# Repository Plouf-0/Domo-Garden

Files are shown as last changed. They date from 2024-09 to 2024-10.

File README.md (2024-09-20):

# Domo-Garden
#### A projet to add domotique in my garden

## 1. Project overview

#### Objective
Design and develop a Zigbee-based sensor network. The network will collect data from various environmental sensors (Thermal, Humidity, PH, ...), communicate wirelessly via Zigbee, and transmit data to a central hub that sends the information to a Home Assistant server via Wi-Fi. The system will also control an electrovalve based on predefined conditions.

#### Key Components:

- ESP32 + Zigbee module for Hub with Wi-Fi connectivity
- EFR32MG22-based sensor nodes
- Temperature, humidity sensors, and other IoT peripherals
- Electrovalve for irrigation control

## 2. Technical Specifications

#### Functional Requirements

    Data Collection: Periodic collection of temperature, humidity, and other sensor data.

    Communication: Use Zigbee for sensor node communication and Wi-Fi for sending data to the server.

    Control: Triggering of an electrovalve based on time or sensor data.

    Hub Features: The hub will aggregate data from up to 30 Zigbee devices and relay it via Wi-Fi to a server.

    Data Transfer Rate: Sensor data will be transmitted periodically, adjustable from 1 minute to 1 hour.

#### Hardware Specifications

    Microcontroller:
        ESP32
        EFR32MG22E224F512IM32

    Power Supply: Battery-powered nodes, possible use of solar panels. Minimum 1-month battery life without recharging. A 1000mAh = 1 year of battery life.

    Radio Frequency: Zigbee protocol.

    Communication Range: Up to 100 meters from hub, with a mesh network to cover distances up to 20 meters between each module.

    Sensors:
        Temperature sensors.
        Humidity sensors.
        Soil moisture sensors.
        Light sensors.
        PH sensors.
        More to come.

#### Software Specifications

    Programming Languages: C/C++ (for embedded systems), Python (for server-side automation).

    Development Environment: Simplicity Studio (for EFR32MG22).
    
    Protocols:
        Zigbee (3.0)
        Wi-Fi for hub (ESP32 or similar)
        MQTT (for data transmission to Home Assistant server).

    Operating System: FreeRTOS (for efficient power management).

#### Performance Metrics

    Battery Life: Minimum 30 days.

    Latency: Data transmission delay < 2 seconds between sensor reading and hub reception.

    Network Coverage: 100-meter total coverage using mesh networking.

## 3. Project Plan

#### Phases of Development

    Phase 1: Requirements Gathering & Research
        Gather requirements for sensors, control mechanisms, and networking.
        Research hardware options, compatibility with Zigbee and Home Assistant.

    Phase 2: Software Development
        Develop firmware for the EFR32MG22E224F512IM40 to read sensors, communicate via Zigbee, and send commands to the electrovalve with the EFR32xG22E Explorer Kit.
        Develop software for the Zigbee hub to manage data collection and Wi-Fi transmission to Home Assistant with the ESP32 and the Zigbee CC2530 Development Board.

    Phase 2^2: Hardware Design
        Design the PCB for sensor nodes (powered by EFR32MG22E224F512IM40).
        Create a schematic for power management (battery, solar charging).
        Select components for the electrovalve control system.
        Design and print the casing.

    Phase 3: Integration with Home Assistant
        Set up the Home Assistant server with Zigbee2MQTT or ZHA.
        Implement data visualization for sensor data.
        Test commands sent from Home Assistant to control the electrovalve.

    Phase 4: Prototyping
        Assemble and test initial sensor nodes and hub.
        Perform range and battery life tests.
        Ensure proper communication between the Zigbee nodes and the hub.

    Phase 6: Field Testing
        Deploy the system in a real environment (garden, yard).
        Monitor sensor performance, network stability, and control system reliability.

    Phase 6: Finalization & Documentation
        Finalize the design based on testing results.
        Prepare full documentation, including schematics, software, and user guide.

## 4. Risk Assessment

    Power Supply Issues: If solar panels are used, energy harvesting efficiency must be tested under various weather conditions.
    Connectivity Range: Trees and obstacles could interfere with Zigbee signals. Extensive field testing will be necessary to determine optimal node placement.
    Data Security: Implement encryption for data transmitted via Zigbee to prevent unauthorized access.
    Component Availability: Verify the supply chain for key components (e.g., EFR32MG22) to avoid potential delays due to shortages.

## 5. Additional Considerations

    OTA (Over-The-Air) Firmware Updates: Consider adding functionality for future remote firmware updates.
    Scalability: Keep flexibility in mind for expanding the network or adding more nodes later.

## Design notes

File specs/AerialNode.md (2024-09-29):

# Domo-Garden
### The node is the modular part where sensors are attached. It gets sensors information and transmit them to the hub via Zigbee.

## 1. Components

- EFR32MG22E224F512IM32
- DHT22
- Photoresistors
- Battery 1000mAh + recharging module (MCP73833)
- CP2102N-Axx-xQFN20 (USB to UART)
- TLV75533PDBV (3-5V to 3.3V)
- Crystal ECS-384-CDX-1983-TR3 

## 2. Alim

The board is powered by USB-C.
The USB-C powers the MCP73833 that recharges the 1000mAh.
The MCP73833 and the battery can power the board by using a TLV75533PDBV to sabilize the voltage to 3.3V.

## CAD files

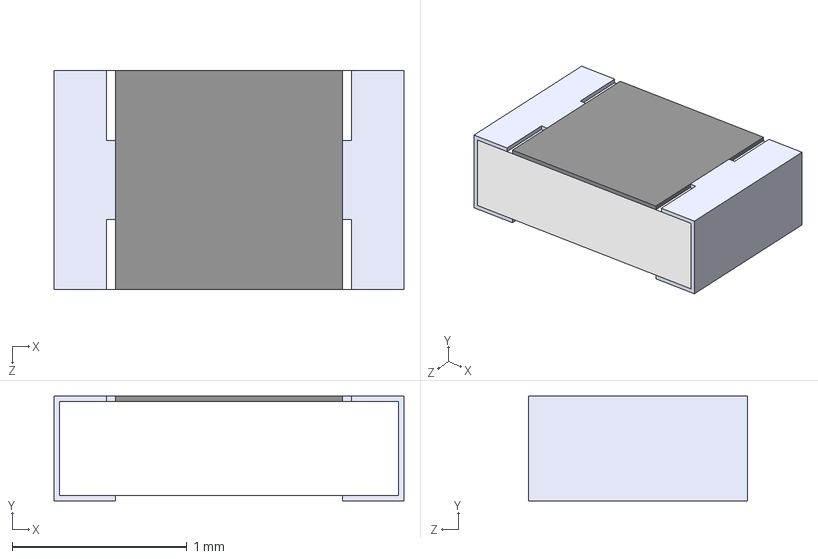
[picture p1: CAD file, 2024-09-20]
PCB/node/Components/capa10uf6.3v_CC0805KKX5R5BB106/CC0805KKX5R5BB106.step
2.00 x 0.6 x 1.25 mm

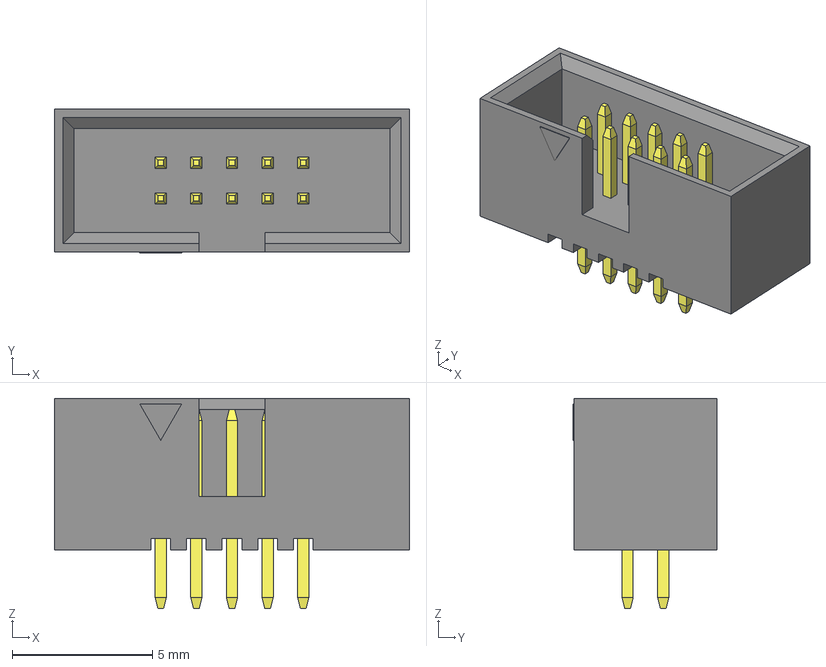
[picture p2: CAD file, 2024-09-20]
PCB/node/Components/EFR32MG22-miniboard-main/eec.models/CNC_Tech_-_3220-10-0100-00.step
12.7 x 5.13 x 7.50 mm

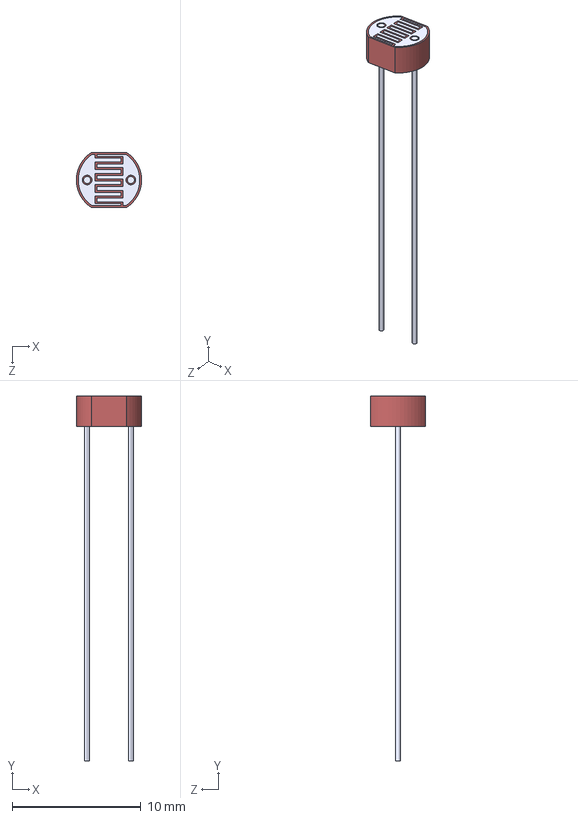
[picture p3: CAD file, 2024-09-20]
PCB/node/Components/photoresistor_PDV-P8003/PDV-P8003.step
5.07 x 28.4 x 4.29 mm

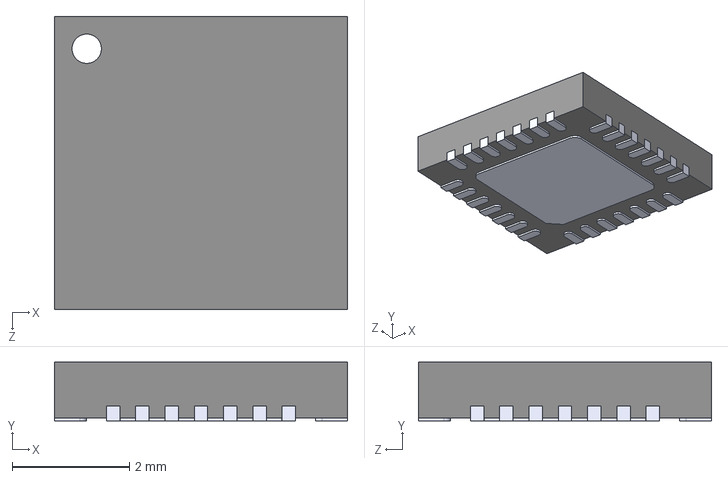
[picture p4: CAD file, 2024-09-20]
PCB/node/Components/Usb-Uart_INTERFACE-CP2102-GMR_QFN28_/INTERFACE-CP2102-GMR_QFN28_.step
5.00 x 1.00 x 5.00 mm

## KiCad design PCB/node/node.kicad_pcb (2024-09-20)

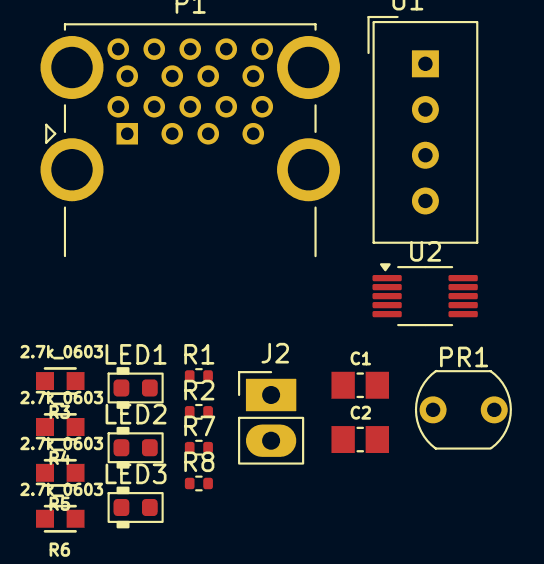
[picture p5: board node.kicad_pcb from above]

Board: 2 copper layers, 18 parts (0 on the bottom side), 12 nets, no tracks yet.

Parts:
C1, C2: 10uF 6.3V; CAPC2012X70
J2: BATT; PinHeader_1x02_P2.54mm_Vertical
LED1: LED_0603_Green; LED_0603_1608Metric
LED2: LED_0603_Yellow; LED_0603_1608Metric
LED3: LED_0603_Red; LED_0603_1608Metric
P1: USB_C_Plug_USB2.0; USB3_A_Molex_48406-0001_Horizontal_Stacked
PR1: R_LDR_5.1x4.3mm_P3.4mm_Vertical
R1, R2, R7, R8: 10k_0402; R_0402_1005Metric
R3, R4, R5, R6: 2.7k_0603; R_0603
U1: DHT22; Aosong_DHT11_5.5x12.0_P2.54mm
U2: MCP73833-xxx-UN; MSOP-10_3x3mm_P0.5mm

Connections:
+3.3V: C2.1, J2.1, R1.1, R2.1, U1.1 (VDD), U2.9 (V_{BAT}), U2.10 (V_{BAT})
DHT GPIO: R1.2, U1.2 (DATA)
GND: C1.2, C2.2, J2.2, R6.2, R7.1, R8.1, U1.4 (GND), U2.5 (V_{SS})
unnamed: C1.1, LED1.2 (A), LED2.2 (A), LED3.2 (A), U2.1 (V_{DD}), U2.2 (V_{DD})
unnamed: LED1.1 (K), R3.1
unnamed: LED2.1 (K), R4.1
unnamed: LED3.1 (K), R5.1
unnamed: R6.1, R7.2, U2.6 (PROG)
unnamed: R4.2, U2.3 (STAT1)
unnamed: R3.2, U2.4 (STAT2)
unnamed: R8.2, U2.8 (THERM)
unnamed: R5.2, U2.7 (~PG)

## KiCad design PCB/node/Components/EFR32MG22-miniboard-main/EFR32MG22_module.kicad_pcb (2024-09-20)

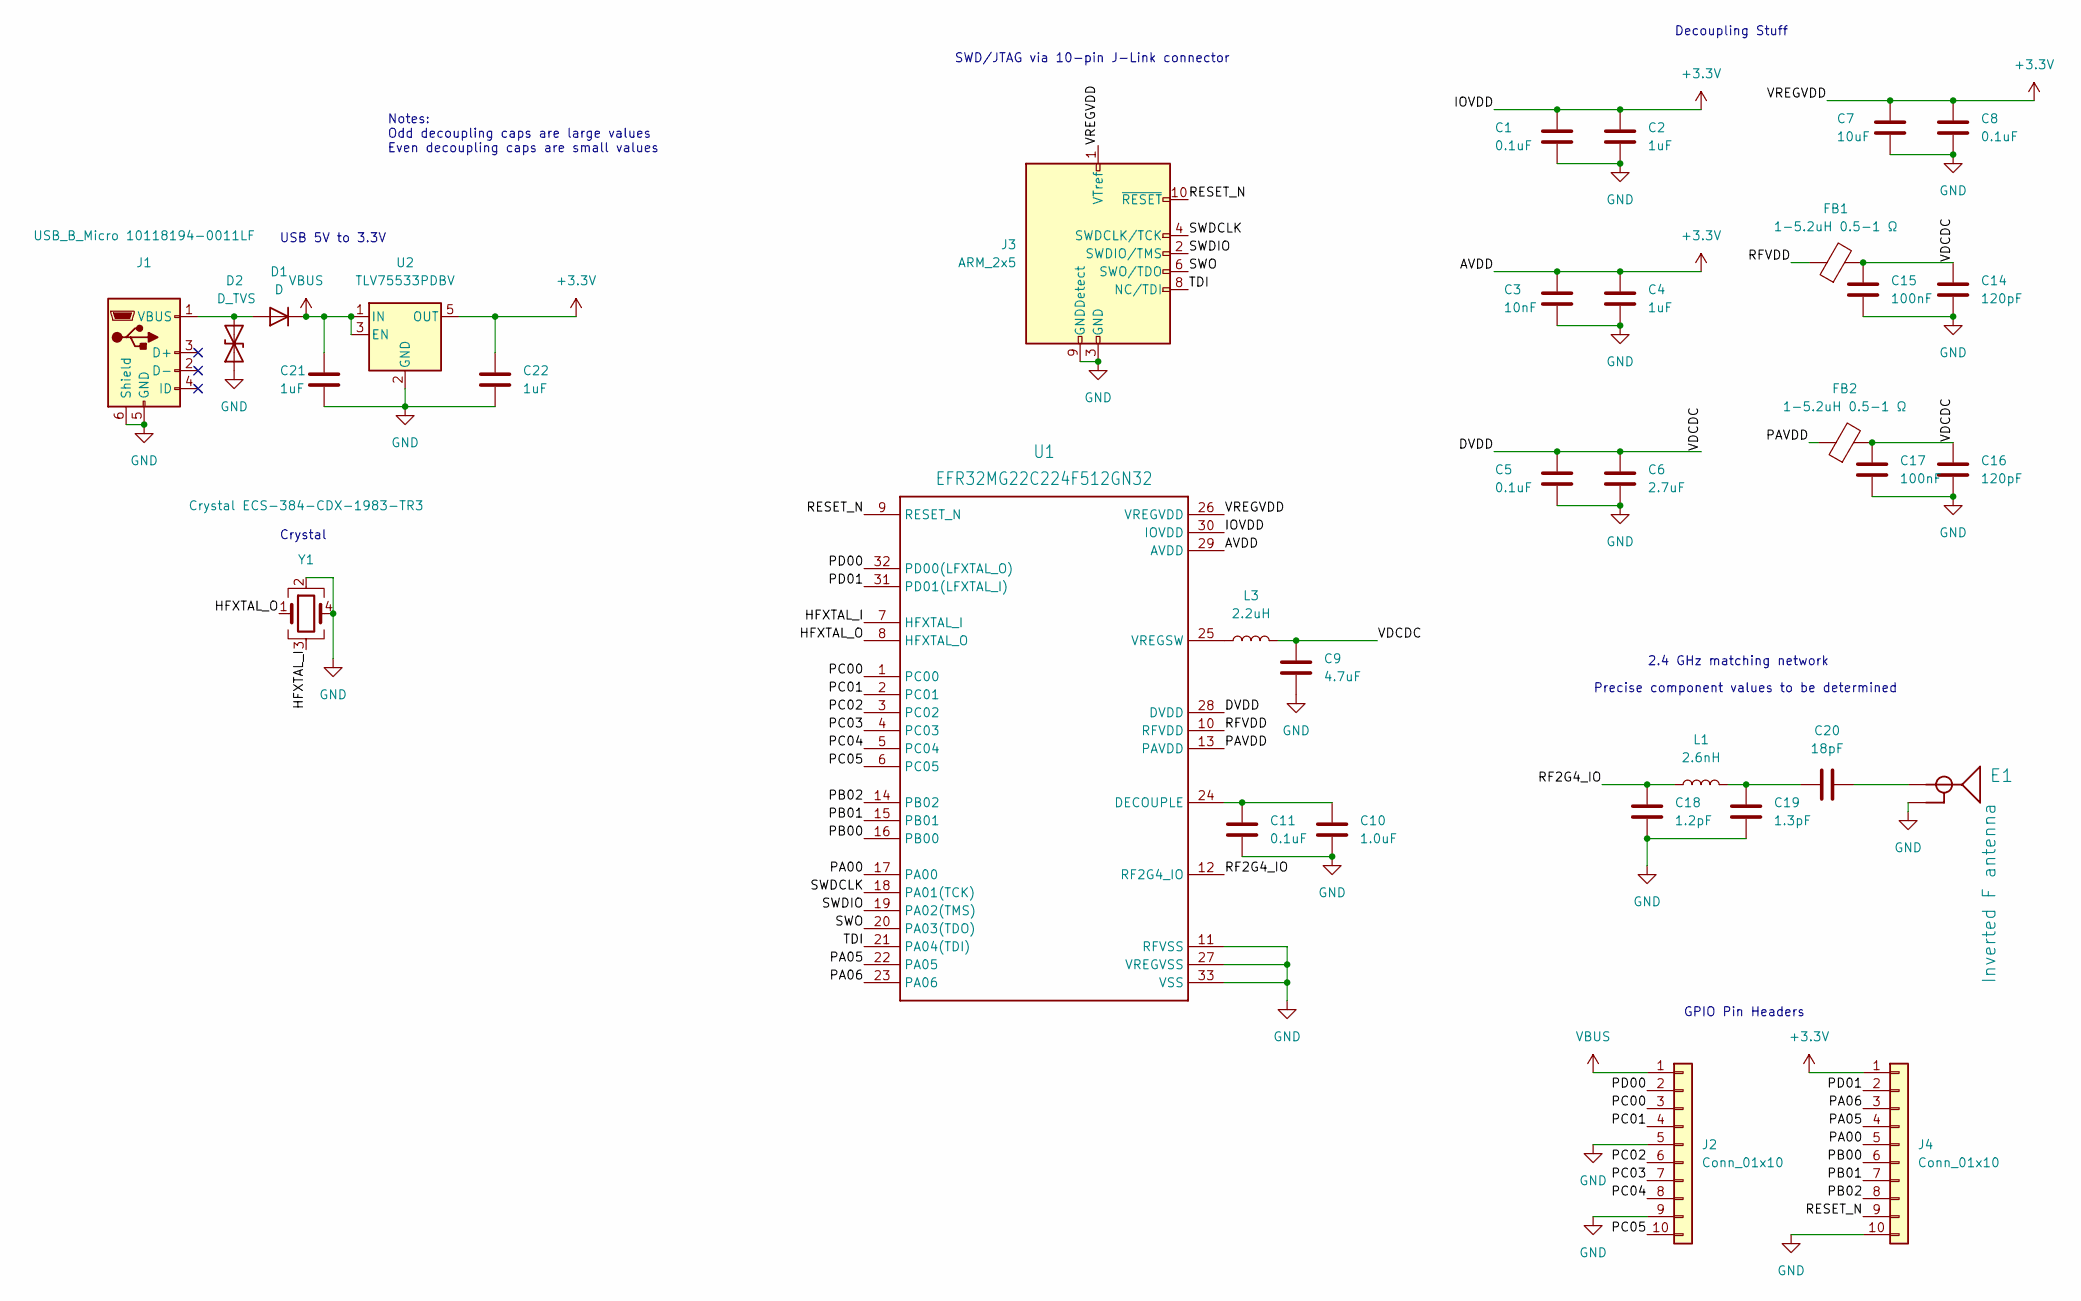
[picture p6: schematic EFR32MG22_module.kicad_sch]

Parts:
C1, C5, C8, C11: 0.1uF; C_0603_1608Metric_Pad1.08x0.95mm_HandSolder
C2, C4, C21, C22: 1uF; C_0603_1608Metric_Pad1.08x0.95mm_HandSolder
C3: 10nF; C_0603_1608Metric_Pad1.08x0.95mm_HandSolder
C6: 2.7uF; C_0603_1608Metric_Pad1.08x0.95mm_HandSolder
C7: 10uF; C_0603_1608Metric_Pad1.08x0.95mm_HandSolder
C9: 4.7uF; C_0603_1608Metric_Pad1.08x0.95mm_HandSolder
C10: 1.0uF; C_0603_1608Metric_Pad1.08x0.95mm_HandSolder
C14, C16: 120pF; C_0603_1608Metric_Pad1.08x0.95mm_HandSolder
C15, C17: 100nF; C_0603_1608Metric_Pad1.08x0.95mm_HandSolder
C18: 1.2pF; C_0603_1608Metric_Pad1.08x0.95mm_HandSolder
C19: 1.3pF; C_0603_1608Metric_Pad1.08x0.95mm_HandSolder
C20: 18pF; C_0603_1608Metric_Pad1.08x0.95mm_HandSolder
D1: D; D_SOD-123
D2: D_TVS; D_0201_0603Metric
E1: Inverted F antenna; TRACE_ANTENNA_2.4GHZ_15.2MM
FB1, FB2: 1-5.2uH 0.5-1 Ω; L_0603_1608Metric_Pad1.05x0.95mm_HandSolder
J1: USB_B_Micro 10118194-0011LF; USB_Micro-B_Amphenol_10118194_Horizontal
J2, J4: Conn_01x10; PinHeader_1x10_P2.54mm_Vertical
J3: ARM_2x5; 322010030000TR
L1: 2.6nH; L_0603_1608Metric_Pad1.05x0.95mm_HandSolder
L3: 2.2uH; L_0805_2012Metric_Pad1.15x1.40mm_HandSolder
U1: EFR32MG22C224F512GN32; QFN-32-1EP_4x4mm_P0.4mm_EP2.9x2.9mm_ThermalVias
U2: TLV75533PDBV; SOT-23-5
Y1: Crystal ECS-384-CDX-1983-TR3; Crystal_SMD_2016-4Pin_2.0x1.6mm

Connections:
+3.3V: C1.1, C2.1, C3.1, C4.1, C7.1, C8.1, C22.2, J3.1 (VTref), J4.1, U1.26 (VREGVDD), U1.29 (AVDD), U1.30 (IOVDD), U2.5 (OUT)
/DVDD: C5.1, C6.1, C9.1, C14.1, C15.1, C16.1, C17.1, FB1.2, FB2.2, L3.2, U1.28 (DVDD)
/HFXTAL_I: U1.7 (HFXTAL_I), Y1.3
/HFXTAL_O: U1.8 (HFXTAL_O), Y1.1
/PA00: J4.5, U1.17 (PA00)
/PA05: J4.4, U1.22 (PA05)
/PA06: J4.3, U1.23 (PA06)
/PAVDD: FB2.1, U1.13 (PAVDD)
/PB00: J4.6, U1.16 (PB00)
/PB01: J4.7, U1.15 (PB01)
/PB02: J4.8, U1.14 (PB02)
/PC00: J2.3, U1.1 (PC00)
/PC01: J2.4, U1.2 (PC01)
/PC02: J2.6, U1.3 (PC02)
/PC03: J2.7, U1.4 (PC03)
/PC04: J2.8, U1.5 (PC04)
/PC05: J2.10, U1.6 (PC05)
/PD00: J2.2, U1.32 (PD00(LFXTAL_O))
/PD01: J4.2, U1.31 (PD01(LFXTAL_I))
/RESET_N: J3.10 (~RESET), J4.9, U1.9 (RESET_N)
/RF2G4_IO: C18.1, L1.1, U1.12 (RF2G4_IO)
/RFVDD: FB1.1, U1.10 (RFVDD)
/SWDCLK: J3.4 (SWDCLK/TCK), U1.18 (PA01(TCK))
/SWDIO: J3.2 (SWDIO/TMS), U1.19 (PA02(TMS))
/SWO: J3.6 (SWO/TDO), U1.20 (PA03(TDO))
/TDI: J3.8 (NC/TDI), U1.21 (PA04(TDI))
GND: C1.2, C2.2, C3.2, C4.2, C5.2, C6.2, C7.2, C8.2, C9.2, C10.2, C11.2, C14.2, C15.2, C16.2, C17.2, C18.2, C19.2, C21.1, C22.1, D2.1 (A1), E1.GND, J1.5 (GND), J1.6 (Shield), J2.5, J2.9, J3.3 (GND), J3.5 (GND), J3.9 (GNDDetect), J4.10, U1.11 (RFVSS), U1.27 (VREGVSS), U1.33 (VSS), U2.2 (GND), Y1.2, Y1.4
unnamed: C10.1, C11.1, U1.24 (DECOUPLE)
unnamed: C19.1, C20.2, L1.2
unnamed: C20.1, E1.ANT (SIGNAL)
unnamed: D1.2 (A), D2.2 (A2), J1.1 (VBUS)
unnamed: L3.1, U1.25 (VREGSW)
VBUS: C21.2, D1.1 (K), J2.1, U2.1 (IN), U2.3 (EN)

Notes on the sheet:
GPIO Pin Headers
Precise component values to be determined
Notes: Odd decoupling caps are large values Even decoupling caps are small values
2.4 GHz matching network
SWD/JTAG via 10-pin J-Link connector
Crystal
Decoupling Stuff
USB 5V to 3.3V

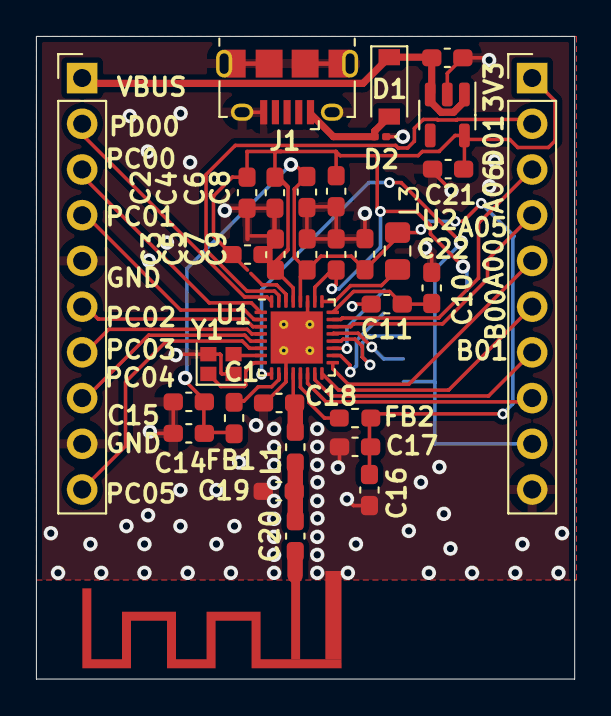
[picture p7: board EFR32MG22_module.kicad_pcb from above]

Board: 2 copper layers, 29.9 x 35.7 mm, 34 parts (1 on the bottom side), 33 nets.

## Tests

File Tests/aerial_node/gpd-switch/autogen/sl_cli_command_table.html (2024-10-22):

# CLI Command Reference

reset sl_zigbee_gpd_af_cli_reset_command

Resets the node.

send-gpdf u8 hex sl_zigbee_gpd_af_cli_send_gpdf

Sends out a GPD command based on the set GPD parameters.

Arguments

- u8Frame type 0 = Data frame, 1 = Maintenance frame.
- hexCommand payload

## zigbee_print

### zigbee_print enable_type

zigbee_print enable_type stack u8 sli_zigbee_debug_print_enable_stack_type_command

Enable/disable debug `stack` print type.

Arguments

- u8Enable/disable

zigbee_print enable_type core u8 sli_zigbee_debug_print_enable_core_type_command

Enable/disable debug `core` print type.

Arguments

- u8Enable/disable

zigbee_print enable_type app u8 sli_zigbee_debug_print_enable_app_type_command

Enable/disable debug `app` print type.

Arguments

- u8Enable/disable

zigbee_print enable_type zcl u8 sli_zigbee_debug_print_enable_zcl_type_command

Enable/disable debug `zcl` print type.

Arguments

- u8Enable/disable

zigbee_print enable_type legacy_af_debug u8 sli_zigbee_debug_print_enable_legacy_af_debug_type_command

Enable/disable debug `legacy app framework debug` print type.

Arguments

- u8Enable/disable

## node

gpd node related commands

node info sl_zigbee_gpd_af_cli_node_info

Prints the GPD node information.

node channel-req sl_zigbee_gpd_af_cli_channel_req

Sends out a channel request command from the GPD.

node comm u8 sl_zigbee_gpd_af_cli_comm_req

Sends out a commissioning request and moves the commissioning state machine based on the parameter provided.

Arguments

- u80x00 - Decommission, 0x01 = A single commissioning GPDF, 0xFF = Start automatic commissioning process

node set-addr hex sl_zigbee_gpd_af_cli_node_set_addr

Sets the address of the GPD node.

Arguments

- hexarray of 8 bit data, where AppId = arg[0], if AppId = 0 then SrcId = arg[1-4] but if AppId = 2 then Endpoint = arg[1] and EUI = arg[2-9]

node set-ac u8 sl_zigbee_gpd_af_cli_node_set_auto_comm

Sets the auto-commission parameter of the GPD node.

Arguments

- u8Auto-commissioning parameter of the GPD node

node set-bidir-param u8 u8 u8 sl_zigbee_gpd_af_cli_node_set_bi_dir_param

Sets bidirectional parameter of the GPD node.

Arguments

- u8rx-after-tx flag.
- u8rx-offset in milliseconds.
- u8rxwindow in milliseconds.

node set-channel u8 sl_zigbee_gpd_af_cli_node_set_channel

Sets the channel of operation for unidirectional GPD or channel for bidirectional commissioning.

Arguments

- u8GPD channel from 11 to 26

node set-sec-key-type u8 sl_zigbee_gpd_af_cli_node_set_sec_key_type

Sets the bidirectional commissioning key type.

Arguments

- u8Key type between 0 and 7

node set-sec-key hex sl_zigbee_gpd_af_cli_node_set_sec_key

Sets the bidirectional key.

Arguments

- hex128 bit key

node set-sec-fc u32 sl_zigbee_gpd_af_cli_node_set_sec_fc

Sets security frame counter.

Arguments

- u32Sec frame counter

node set-sec-level u8 sl_zigbee_gpd_af_cli_node_set_sec_level

Sets security level. 0 = No security, 1 = RESERVED, 2 = Authentication only, 3 = Encrypted and Authenticated

Arguments

- u8Sec level between 0 to 3.

## switch

switch related commands

switch toggle sl_zigbee_gpd_af_cli_switch_toggle

Sends a toggle command.

switch sleep sl_zigbee_gpd_af_cli_switch_sleep

sets gpd as a sleepy device.

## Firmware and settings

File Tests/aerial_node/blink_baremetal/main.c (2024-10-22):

/***************************************************************************//**
 * @file main.c
 * @brief main() function.
 *******************************************************************************
 * # License
 * <b>Copyright 2020 Silicon Laboratories Inc. www.silabs.com</b>
 *******************************************************************************
 *
 * The licensor of this software is Silicon Laboratories Inc. Your use of this
 * software is governed by the terms of Silicon Labs Master Software License
 * Agreement (MSLA) available at
 * www.silabs.com/about-us/legal/master-software-license-agreement. This
 * software is distributed to you in Source Code format and is governed by the
 * sections of the MSLA applicable to Source Code.
 *
 ******************************************************************************/
#include "sl_component_catalog.h"
#include "sl_system_init.h"
#include "app.h"
#if defined(SL_CATALOG_POWER_MANAGER_PRESENT)
#include "sl_power_manager.h"
#endif
#if defined(SL_CATALOG_KERNEL_PRESENT)
#include "sl_system_kernel.h"
#else // SL_CATALOG_KERNEL_PRESENT
#include "sl_system_process_action.h"
#endif // SL_CATALOG_KERNEL_PRESENT

int main(void)
{
  // Initialize Silicon Labs device, system, service(s) and protocol stack(s).
  // Note that if the kernel is present, processing task(s) will be created by
  // this call.
  sl_system_init();

  // Initialize the application. For example, create periodic timer(s) or
  // task(s) if the kernel is present.
  app_init();


#if defined(SL_CATALOG_KERNEL_PRESENT)
  // Start the kernel. Task(s) created in app_init() will start running.
  sl_system_kernel_start();
#else // SL_CATALOG_KERNEL_PRESENT


  while (1) {
    // Do not remove this call: Silicon Labs components process action routine
    // must be called from the super loop.
    sl_system_process_action();

    // Application process.
    app_process_action();

#if defined(SL_CATALOG_POWER_MANAGER_PRESENT)
    // Let the CPU go to sleep if the system allows it.
    sl_power_manager_sleep();
#endif
  }
#endif // SL_CATALOG_KERNEL_PRESENT
}

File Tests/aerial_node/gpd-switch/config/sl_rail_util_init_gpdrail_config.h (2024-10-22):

/***************************************************************************//**
 * @file
 * @brief
 *******************************************************************************
 * # License
 * <b>Copyright 2020 Silicon Laboratories Inc. www.silabs.com</b>
 *******************************************************************************
 *
 * SPDX-License-Identifier: Zlib
 *
 * The licensor of this software is Silicon Laboratories Inc.
 *
 * This software is provided 'as-is', without any express or implied
 * warranty. In no event will the authors be held liable for any damages
 * arising from the use of this software.
 *
 * Permission is granted to anyone to use this software for any purpose,
 * including commercial applications, and to alter it and redistribute it
 * freely, subject to the following restrictions:
 *
 * 1. The origin of this software must not be misrepresented; you must not
 *    claim that you wrote the original software. If you use this software
 *    in a product, an acknowledgment in the product documentation would be
 *    appreciated but is not required.
 * 2. Altered source versions must be plainly marked as such, and must not be
 *    misrepresented as being the original software.
 * 3. This notice may not be removed or altered from any source distribution.
 *
 ******************************************************************************/

#ifndef SL_RAIL_UTIL_INIT_GPDRAIL_CONFIG_H
#define SL_RAIL_UTIL_INIT_GPDRAIL_CONFIG_H

#include "rail_types.h"

// <<< Use Configuration Wizard in Context Menu >>>

// <h> RAIL Init Configuration
// <e SL_RAIL_UTIL_INIT_GPDRAIL_ENABLE> Initialize RAIL
// <i> Default: 1
#define SL_RAIL_UTIL_INIT_GPDRAIL_ENABLE 1

// <h> Project Configuration
// <q SL_RAIL_UTIL_INIT_RADIO_CONFIG_SUPPORT_GPDRAIL_ENABLE> Enable Radio Configurator Support (include rail_config.c/h generated by Radio Config)
// <i> Default: 0
#define SL_RAIL_UTIL_INIT_RADIO_CONFIG_SUPPORT_GPDRAIL_ENABLE 0
// <q SL_RAIL_UTIL_INIT_INIT_COMPLETE_CALLBACK_GPDRAIL_ENABLE> Enable RAIL Init Complete Callback
// <i> Default: 0
#define SL_RAIL_UTIL_INIT_INIT_COMPLETE_CALLBACK_GPDRAIL_ENABLE 1
// </h>

// <e SL_RAIL_UTIL_INIT_PROTOCOLS_GPDRAIL_ENABLE> Protocol Configuration
// <i> Default: 0
#define SL_RAIL_UTIL_INIT_PROTOCOLS_GPDRAIL_ENABLE 1
// <h> Radio Configuration
// <o SL_RAIL_UTIL_INIT_PROTOCOL_GPDRAIL_DEFAULT> Default Radio Configuration
// <SL_RAIL_UTIL_PROTOCOL_PROPRIETARY=> Proprietary (use rail_config.c/h)
// <SL_RAIL_UTIL_PROTOCOL_BLE_1MBPS=> Bluetooth LE 1Mbps
// <SL_RAIL_UTIL_PROTOCOL_BLE_2MBPS=> Bluetooth LE 2Mbps
// <SL_RAIL_UTIL_PROTOCOL_BLE_CODED_125KBPS=> Bluetooth LE Coded 125Kbps
// <SL_RAIL_UTIL_PROTOCOL_BLE_CODED_500KBPS=> Bluetooth LE Coded 500Kbps
// <SL_RAIL_UTIL_PROTOCOL_BLE_QUUPPA_1MBPS=> Bluetooth Quuppa 1Mbps
// <SL_RAIL_UTIL_PROTOCOL_IEEE802154_2P4GHZ=> IEEE 802.15.4 2.4GHz
// <SL_RAIL_UTIL_PROTOCOL_IEEE802154_2P4GHZ_ANTDIV=> IEEE 802.15.4 2.4GHz, antenna diversity
// <SL_RAIL_UTIL_PROTOCOL_IEEE802154_2P4GHZ_COEX=> IEEE 802.15.4 2.4GHz, coexistence
// <SL_RAIL_UTIL_PROTOCOL_IEEE802154_2P4GHZ_ANTDIV_COEX=> IEEE 802.15.4 2.4GHz, antenna diversity, coexistence
// <i> Default: SL_RAIL_UTIL_PROTOCOL_BLE_1MBPS
#define SL_RAIL_UTIL_INIT_PROTOCOL_GPDRAIL_DEFAULT  SL_RAIL_UTIL_PROTOCOL_IEEE802154_2P4GHZ
// <o SL_RAIL_UTIL_INIT_PROTOCOL_PROPRIETARY_GPDRAIL_INDEX> Proprietary Radio Config Index (if Proprietary radio config selected, use index X of channelConfigs[X])
// <0-255:1>
// <i> Default: 0
#define SL_RAIL_UTIL_INIT_PROTOCOL_PROPRIETARY_GPDRAIL_INDEX 0
// </h>
// </e>

// <e SL_RAIL_UTIL_INIT_CALIBRATIONS_GPDRAIL_ENABLE> Calibration Configuration
// <i> Default: 0
#define SL_RAIL_UTIL_INIT_CALIBRATIONS_GPDRAIL_ENABLE 1
// <h> Calibration Notifications
// <q SL_RAIL_UTIL_INIT_CALIBRATION_TEMPERATURE_NOTIFY_GPDRAIL_ENABLE> Enable Temperature Calibration Notifications (RAIL_EVENT_CAL_NEEDED radio event issued when temperature calibrations needed, for example VCO calibration)
// <i> Default: 0
#define SL_RAIL_UTIL_INIT_CALIBRATION_TEMPERATURE_NOTIFY_GPDRAIL_ENABLE 1
// <q SL_RAIL_UTIL_INIT_CALIBRATION_ONETIME_NOTIFY_GPDRAIL_ENABLE> Enable One-time Calibration Notifications (RAIL_EVENT_CAL_NEEDED radio event issued when one-time calibrations needed, for example IR calibration)
// <i> Default: 0
#define SL_RAIL_UTIL_INIT_CALIBRATION_ONETIME_NOTIFY_GPDRAIL_ENABLE 1
// </h>
// </e>
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

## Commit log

2024-09-12 init PCB project
    [project.kicad_pcb, project.kicad_sch]
2024-09-20 update pcb
    [CC0805KKX5R5BB106.step, CNC_Tech_-_3220-10-0100-00.step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]
2024-09-29 change to add jlink
    [CC0805KKX5R5BB106.step, CNC_Tech_-_3220-10-0100-00.step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]
2024-10-22 creation tests
    [node.kicad_sch]
